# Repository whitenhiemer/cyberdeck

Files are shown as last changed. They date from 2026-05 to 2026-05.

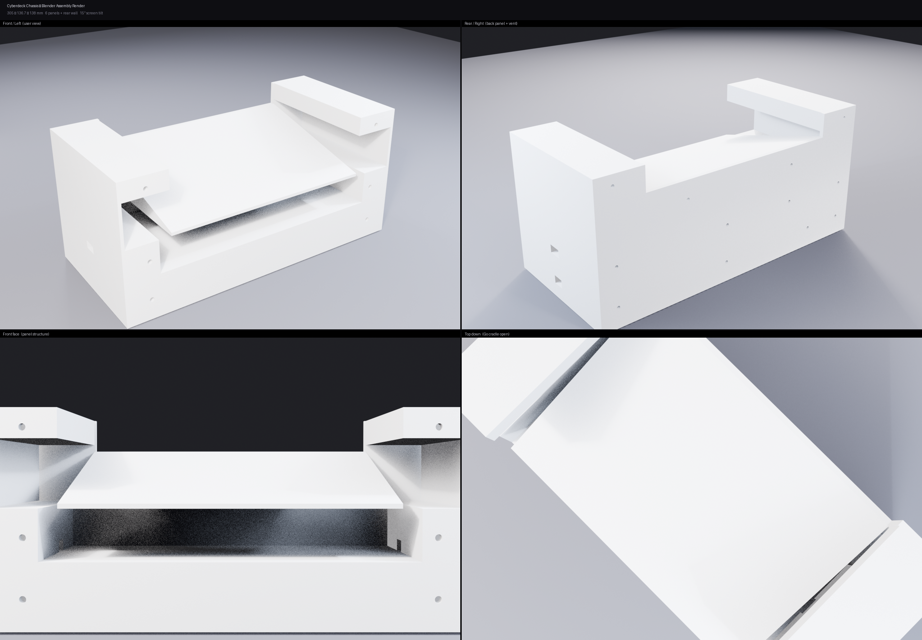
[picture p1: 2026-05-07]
cad/chassis_blender.png

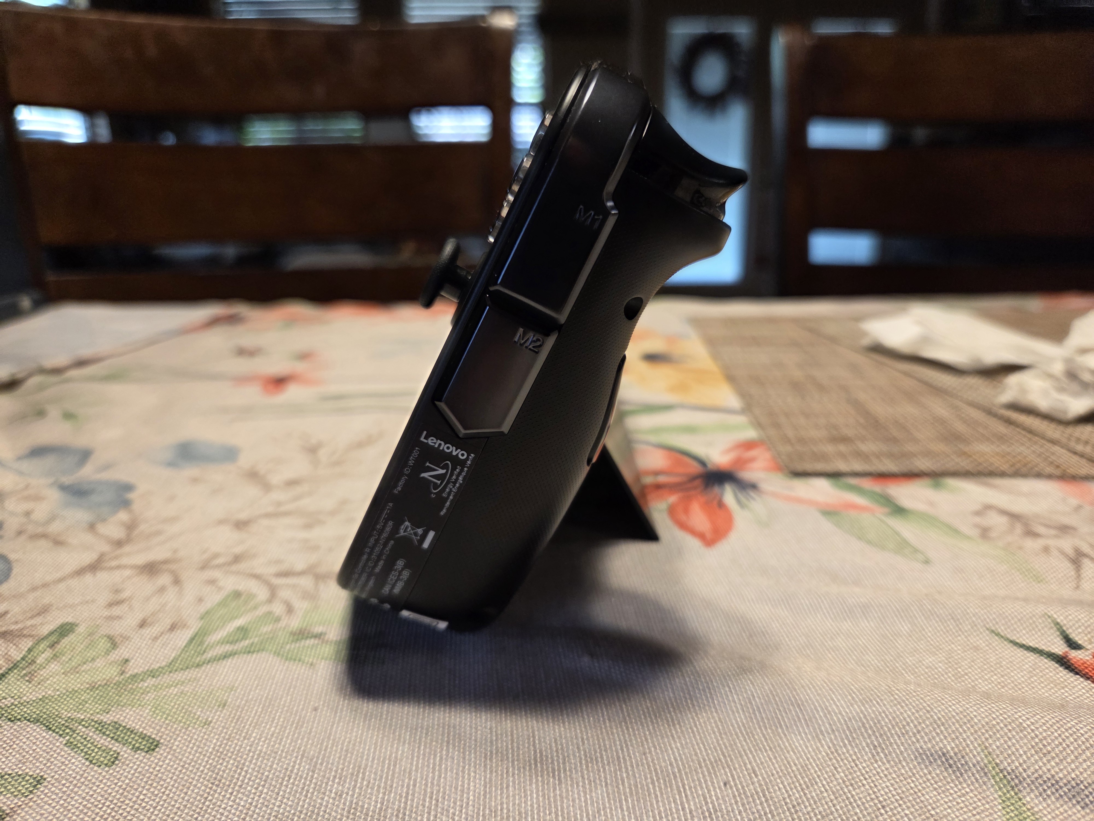
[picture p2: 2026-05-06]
photos/20260506_140101.jpg

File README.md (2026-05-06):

# Cyberdeck

A 3D-printed chassis that turns a Lenovo Legion Go into a portable cyberdeck workstation. Non-destructive — the Go sits in a cradle and can be removed.

## Hardware

| Component | Model | Dimensions |
|---|---|---|
| Brain | Lenovo Legion Go (83E1, 8APU1) | 298.83 x 131 x 40.7mm (with controllers) |
| Keyboard | Planck V7 (USB-C) | 234 x 81 x 33mm |
| Hub | MOKiN 13-in-1 USB-C dock | 130 x 55 x 15mm |
| Battery | OHOVIV 50000mAh power bank | 134 x 70 x 34mm |
| Printers | Ender 3 / Ender 5 | 220x220mm bed |

## Design

- **Form:** Landscape slab, three horizontal rows
- **Tilt:** 15° wedge cradle for the Go (screen angles toward user)
- **Controllers:** Detachable — chassis side channels open at bottom for slide-out removal
- **Back:** Closed rear wall with open vent cutout behind Go exhaust; 5mm kickstand clearance gap
- **Battery:** Removable sliding bay, exits from bottom edge

```
┌──────────[A]──────────┬──────────[B]──────────┐  ← Go cradle (62mm tall)
│  controller rail (L)  │  controller rail (R)  │
│    [ Legion Go cradle — 15° wedge ]            │
├──────────[C]──────────┬──────────[D]───────────┤  ← Planck + dock (36mm tall)
│    [ Planck bay ]     │  [ dock bay ]          │
├──────────[E]──────────┴──────────[F]───────────┤  ← Battery (40mm tall)
│       [ battery bay — slides out from bottom ] │
└────────────────────────────────────────────────┘
  Total: 305 x 138mm face, ~314mm front-to-back
```

## CAD

FreeCAD Python macros in `cad/`. Each panel is a standalone script — open FreeCAD, run the macro via **Macro → Macros**, and it generates and saves the `.FCStd` file.

| File | Description |
|---|---|
| `panel_a.py` | Go cradle, left half — wedge cavity + left controller channel |
| `panel_b.py` | Go cradle, right half — wedge cavity + right controller channel |
| `panel_c.py` | Planck bay, left half |
| `panel_d.py` | Planck bay, right half (dock bay on right) |
| `panel_e.py` | Battery bay, left half |
| `panel_f.py` | Battery bay, right half (USB-C port cutout) |
| `rear_wall.py` | Rear structural wall with Go exhaust vent cutout |

All panels use M3 bolts + alignment pins at seams (holes TBD once final dimensions are locked).

## Open Items

- [ ] Controller rail groove cross-section — needs calipers on Go side edge
- [ ] Final chassis outer dimensions
- [ ] Panel split lines and fastener locations
- [ ] Model controller rail extensions (left + right)
- [ ] Add M3 bolt holes and alignment pins at seams
- [ ] Internal cable routing (Planck USB-C → dock)

## Reference Photos

`photos/` — Legion Go back face, side rail profile, controller connection end.

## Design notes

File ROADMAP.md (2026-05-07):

# Cyberdeck Build Roadmap

## Hardware

- **Brain:** Lenovo Legion Go (83E1, 8APU1)
- **Keyboard:** Planck (USB-C)
- **Hub:** MOKiN 13-in-1 USB-C docking station
- **Printers:** Ender 3 / Ender 5 (220x220mm bed)

## Design Spec

| Element | Decision |
|---|---|
| Form factor | Landscape slab |
| Integration | Non-destructive (Legion Go cradle) |
| Controllers | Detachable, re-attachable via side rails |
| Keyboard | Planck integrated, internal USB-C routing |
| Hub | MOKiN 13-in-1, ports exposed on right edge |
| Screen tilt | 10-15° wedge cradle |
| Back | Closed, structural rear wall |
| Dock placement | Rear wall cavity (ports → right edge cutouts) |
| Battery | OHOVIV 50000mAh, 3rd row, removable sliding bay (exits bottom edge) |
| Handle | Top bar (primary); recessed side grip (backup/iteration) |
| Aesthetic | Utilitarian / functional |

## Known Dimensions

| Component | Dimensions (mm) | Notes |
|---|---|---|
| Legion Go (with controllers) | 298.83 x 131 x 40.7 | 854g |
| Legion Go (base only) | 210 x 131 x 20.1 | 640g |
| Controller (each) | 44.8 x 136.7 x 42.25mm | 210g, own 900mAh battery |
| Controller width per side | ~44.4mm | matches (298.83 - 210) / 2 |
| Controller overhang (height) | +5.7mm over Go base | 136.7mm vs 131mm — protrudes top/bottom |
| Controller thickness overhang | +1.55mm over Go body | 42.25mm vs 40.7mm — bulges beyond Go profile |
| Controller connection | Pogo pins + physical rail | no electrical replication needed in chassis |
| Planck keyboard (V7) | 234 x 81 x 33mm | 510g assembled, 19mm key spacing |
| MOKiN dock | 130 x 55 x 15mm | built-in USB-C cable 6-8", ports on both long sides |
| OHOVIV 50000mAh power bank | 134 x 70 x 34mm | 613g, 22.5W, USB-C + 2x USB-A |

## Chassis Estimates

| Dimension | Value | Basis |
|---|---|---|
| Chassis width | ~305mm | Go full width + side walls |
| Chassis depth (Y) | 136.7mm | All rows unified — set by controller front-to-back extent |
| Chassis height | ~314mm | 131mm Go + ~93mm Planck + ~80mm battery + seams |
| Panel half width | ~150mm | fits 220mm bed |
| Back wall height (at 15°) | +35mm over front | tan(15°) × 131mm |
| Total weight (est.) | ~2.3kg | Go 854g + Planck 510g + bank 613g + chassis ~300g |

## Panel Layout

```
┌──────────[A]──────────┬──────────[B]──────────┐
│  controller rail (L)  │  controller rail (R)  │
│    [ Legion Go cradle (wedge, 10-15°) ]        │
├──────────[C]──────────┬──────────[D]───────────┤
│    [ Planck bay ]     │  [ dock bay ]          │
│                       │  (ports → right edge)  │
├──────────[E]──────────┴──────────[F]───────────┤
│       [ battery bay — slides out from bottom ] │
└────────────────────────────────────────────────┘
```

Side profile:
```
         ____________
        /  Go screen \  ← 10-15° tilt
       /   (20.1mm)  \
______/________________\______
[    Planck    ] [ dock  ]       ← flat base
```

## Phase 1 — Measurements & Dimensions

- [x] Legion Go body dimensions (base + with controllers)
- [x] Controller rail mechanism (slide top-to-bottom, latch at bottom — Joy-Con style)
- [ ] Controller rail groove profile (cross-section depth/width — requires calipers on Go side edge)
- [x] Planck keyboard outer dimensions (234 x 81 x 33mm with acrylic case)
- [x] MOKiN dock outer dimensions (130 x 55 x 15mm)
- [x] Verify screen area is not obstructed — cradle open at y=0, 5.4mm above screen rear edge, 11mm side clearance
- [ ] Define final chassis outer dimensions
- [ ] Determine exact tilt angle (10-15°)
- [ ] Define panel split lines and fastener locations

## Phase 2 — CAD Design

- [x] Choose CAD tool (FreeCAD macros)
- [x] Model panel A — Go cradle top-left
- [x] Model panel B — Go cradle top-right
- [x] Model panel C — Planck bay bottom-left
- [x] Model panel D — dock bay bottom-right
- [x] Model controller rail extensions (left + right) — groove profile placeholder, needs calipers
- [x] Model rear wall / closed back
- [x] Add M3 heat insert holes and alignment pins at panel seams
- [x] Internal cable routing channels (Planck USB-C → dock)
- [x] Model horizontal seam angle bracket clips (separate printed parts, 2 per seam × 2 seams = 4 total)
- [x] Round all sharp external edges — 1.5mm chamfer on front-face and outer-side corners (apply_chamfers.py)
- [x] Fit check / dry assembly review (62/62 software geometry checks pass)

## Variant: No-Rails (cad/no-rails/)

Alternative design for use as handheld — controllers detach and the Go is removed from the chassis entirely.

- [x] Panel A/B without controller rail channels (`cad/no-rails/panel_a.py`, `panel_b.py`)
- [x] Geometric fit check (18/18 pass — same rear wall, brackets, C–F panels)
- [x] Chamfer script for no-rails A/B (`cad/no-rails/apply_chamfers.py`)
- Panels C, D, E, F, rear_wall, bracket_clip — unchanged, use main `cad/` versions

Key difference: 46.5mm solid outer walls in place of 3mm wall + 40mm controller pocket. Go base (210mm) cradles identically; controllers are not accommodated.

## Phase 3 — Prototyping

- [ ] PLA first for fit/tolerance verification, then professional ABS or acrylic print for final
- [ ] Print test pieces at panel seams (fit tolerances)
- [ ] Print controller rail mockup
- [ ] Adjust tolerances based on test prints
- [ ] Print full panels (likely 8-12 hour prints each)
- [ ] Dry fit all panels with hardware

## Phase 4 — Assembly

- [ ] Install M3 heat-set inserts
- [ ] Mount Legion Go in cradle
- [ ] Mount Planck in bay
- [ ] Mount dock in bay, route USB-C to Go
- [ ] Attach controller rails
- [ ] Final fit and finish (sanding, filler if needed)

## Phase 5 — Iteration

- [ ] Evaluate ergonomics (tilt angle, keyboard position)
- [ ] Evaluate top bar handle — if awkward, model recessed side grip variant
- [ ] Add any cable management details
- [ ] Consider paint / surface finish
- [ ] Document final design for reproducibility

## Notes

- All panel seams use M3 bolts + alignment pins
- Machine-specific local configs (Go firmware, etc.) never committed
- Controller rails: slide downward to remove — chassis side channels open at bottom
- Controllers are 5.7mm taller than Go base — top bar must clear controller tops
- Controller thickness (42.25mm) slightly exceeds Go body (40.7mm) — side channel needs clearance
- Pogo pins handle electrical connection — chassis only needs to replicate physical rail groove
- Rail groove cross-section still needs calipers before finalizing side panel CAD
- Battery bay slides out from bottom edge; USB-C port exposed via cutout, dock cable connects manually
- Battery bay retention: printed latch or M3 thumb screw

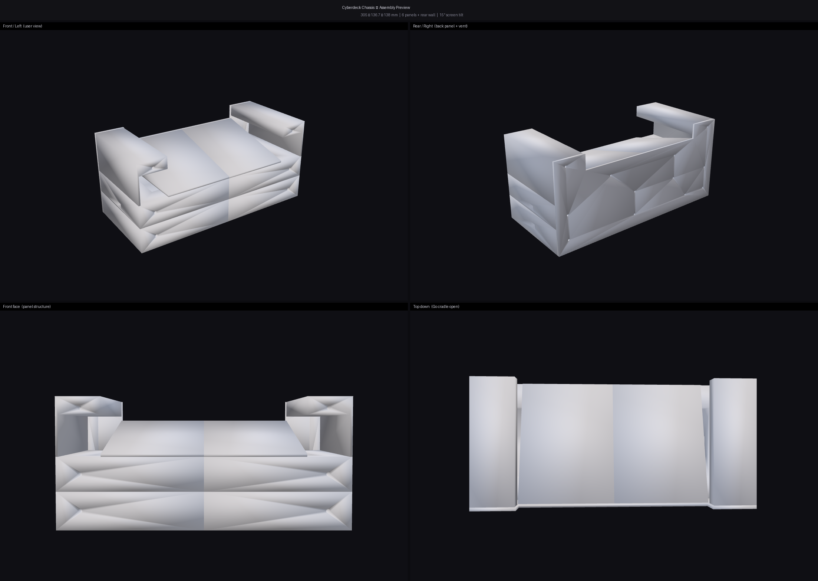
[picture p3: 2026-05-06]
cad/chassis_hq.png

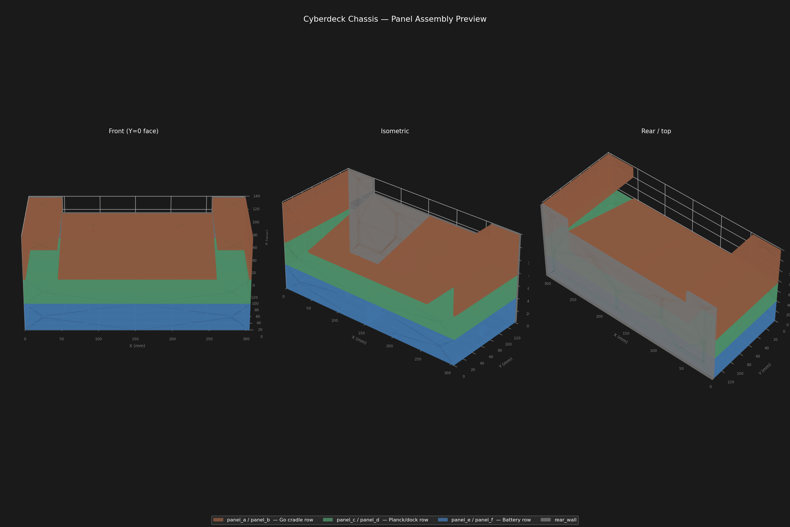
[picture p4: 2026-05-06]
cad/chassis_preview.png

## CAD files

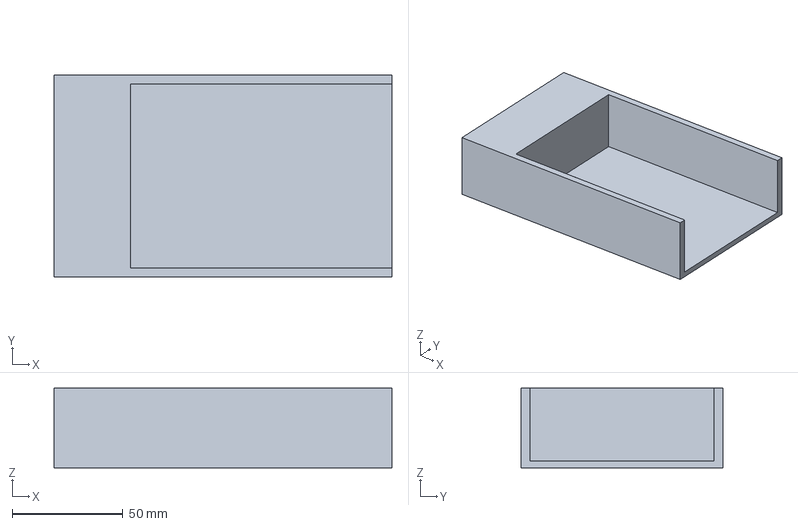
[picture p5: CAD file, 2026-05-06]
cad/panel_c.FCStd
152.5 x 91.0 x 36.0 mm

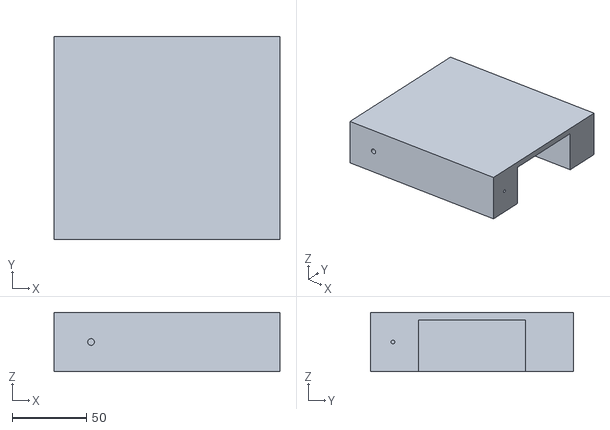
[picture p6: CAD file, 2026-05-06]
cad/stl/panel_e.stl
152.5 x 136.7 x 40.0

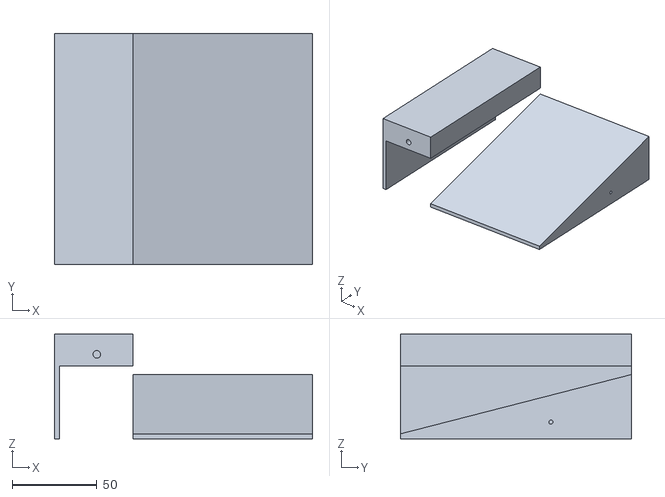
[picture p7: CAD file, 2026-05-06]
cad/stl/panel_a.stl
152.5 x 136.7 x 62.0

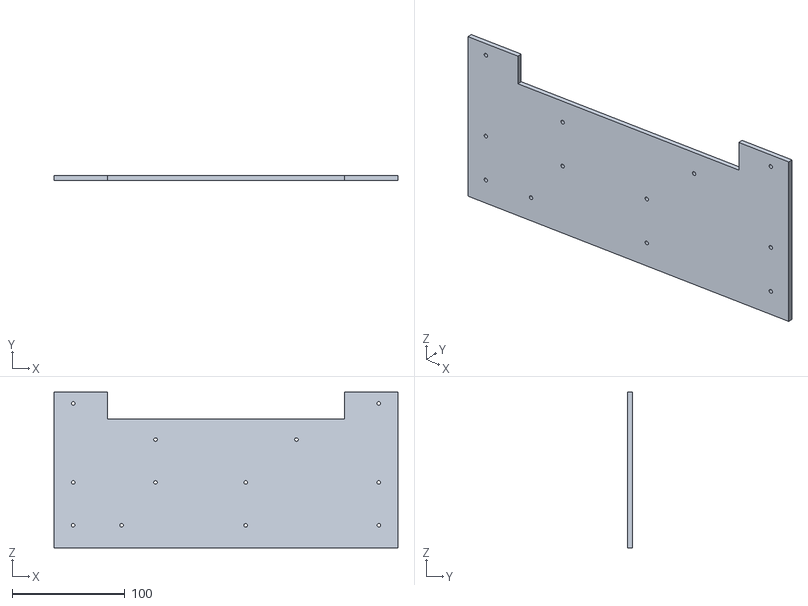
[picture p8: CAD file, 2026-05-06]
cad/stl/rear_wall.stl
305.0 x 4.00 x 138.0

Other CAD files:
cad/panel_d.FCStd
cad/stl/panel_f.stl
cad/stl/panel_b.stl
cad/stl/panel_c.stl
cad/stl/panel_d.stl

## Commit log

2026-05-06 Initial cyberdeck project roadmap
    Legion Go slab cyberdeck with integrated Planck keyboard and MOKiN dock.
    Non-destructive chassis, 10-15° screen tilt, 4-panel split for Ender 3/5.
2026-05-06 Add Legion Go dimensions and chassis estimates to roadmap
    Known dimensions populated for Go base and with-controllers measurements.
    Chassis estimated at ~305x234mm, panel halves ~150mm (fits 220mm bed).
2026-05-06 Add Planck V7 dimensions to roadmap
    234x81x33mm with acrylic case. Planck thickness (33mm) exceeds Go base
    (20.1mm) — Planck section becomes structural floor of the slab.
2026-05-06 Add OHOVIV power bank to roadmap
    134x70x34mm, 613g, 50000mAh. Placement TBD — 3rd row adds ~80mm to
    chassis height; rear compartment is tight at 70mm wide. ~2.3kg total.
2026-05-06 Add battery row layout: 6-panel chassis, removable sliding bay
    Battery slides out from bottom edge with latch/thumb screw retention.
    Chassis height grows to ~314mm, est. total weight ~2.3kg.
2026-05-06 Document controller rail mechanism: slide down to remove
    Controllers detach by sliding downward (not upward). Chassis side panels
    need channels open at the bottom. Rail profile dimensions still TBD.
2026-05-06 Add full controller specs and design implications
    Controllers: 44.8x136.7x42.25mm, 210g each, own 900mAh battery.
    Key constraints: 5.7mm height overhang over Go base (affects top bar),
    1.55mm thickness overhang (affects side channel clearance).
    No electrical replication needed — pogo pins are Go-native.
2026-05-06 Add cad/ directory and gitignore for FreeCAD files
2026-05-06 Add Panel C FreeCAD macro (Planck bay, left half)
    Parametric Part workbench script: 152.5x91x36mm panel with 33mm deep
    Planck pocket (118x83mm in left panel, continues into Panel D).
2026-05-06 Add Panel D FreeCAD macro (Planck bay, right half)
    118mm Planck pocket from seam face, 34.5mm solid right outer wall.
    Mates with Panel C to form complete 236x83x33mm Planck recess.
2026-05-06 Add Panel E+F FreeCAD macros (battery bay row)
    Open-bottom tray, 136x72x35mm cavity (1mm clearance).
    Battery centered in chassis, 5mm top wall, 68mm per panel half.
    Panel F includes USB-C port cutout on right face.
2026-05-06 Add Panel A+B FreeCAD macros (Go cradle row)
    Wedge cradle at 15° tilt (parameterized via TILT_DEG), controller rail
    placeholder channels open at bottom for slide-out removal. Cavity and
    controller pocket dimensions are symmetric across the A/B seam.
2026-05-06 Add rear wall macro and reference photos
    Rear wall: 305 x 4 x 138mm, open vent cutout (210 x 24mm) aligned to
    Go exhaust zone. 5mm kickstand clearance gap between panel rear face and
    wall inner face keeps kickstand protected without blocking airflow.
    Photos: Go back face, side rail profile, controller connection end.
2026-05-06 Add README
    Hardware specs, chassis layout, CAD macro index, and open items list.
2026-05-06 Add USB-C cable routing channels to Panel C and D
    14x8mm slot through Panel C left wall and Panel D right wall, centered
    in the Planck pocket, flush with the pocket floor. Sized to pass a
    USB-C connector for tool-free keyboard and battery replacement.
2026-05-06 Add M3 heat insert holes and alignment pins to all panels
    All panels: rear face heat insert holes (4.5mm dia x 6mm) at positions
    verified clear of all pockets — rear wall M3 bolts are the primary
    structural connection. Alignment pin holes (2.5mm dia x 5mm) at each
    vertical seam face, y=89mm rear margin (only zone solid across all rows).
    Rear wall: 12 matching M3 clearance holes (3.2mm) at all insert positions.
    [panel_c.FCStd, panel_d.FCStd]
2026-05-06 Update Phase 2 roadmap: mark completed items, add angle bracket clips
2026-05-06 Add angle bracket clips and front face inserts
    bracket_clip.py: two bracket sizes (76mm for AB-CD seam, 46mm for CD-EF
    seam), 20x4mm cross-section, M3 clearance holes at each end. Print 2x
    each. Mount to chassis front face with M3x10 bolts into panel inserts.
    All panels: front face heat insert holes (4.5mm x 6mm) at positions
    verified solid at y=0. Panel C/D insert at z=18mm serves both brackets
    (shared position). Brackets span the horizontal seams without modifying
    the panel geometry beyond adding these insert holes.
2026-05-06 Add controller rail extension guide macro (rail_ext.py)
    Press-fit guide blocks for left and right controller pockets in AB panels.
    8mm extension below panel face with Go-side-rail groove (placeholder profile),
    4mm retention tab, and 45° entry chamfer for alignment on controller re-attachment.
    Groove profile marked as placeholder pending caliper measurement of Go side rail.
    Mark rail extensions and angle bracket clips as complete in ROADMAP.
2026-05-06 Add STL exports, render script, and chassis preview image
    Add export_stl.py (FreeCADCmd batch exporter), render_chassis.py
    (trimesh + matplotlib 3-view assembly render), and generated STL/PNG
    outputs. Update .gitignore to exclude FCStd and pycache. Add edge
    rounding to Phase 2 roadmap.
    [panel_a.stl, panel_b.stl, panel_c.stl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]
2026-05-06 Unify all panel rows to 136.7mm depth for flat rear wall
    Set PANEL_H=136.7 on panels C, D, E, F (was 91mm). All rows now match
    the AB row depth set by controller front-to-back extent. Moves alignment
    pins from y=89 (now inside Planck pocket / battery cavity) to y=15 (solid
    front section for all affected panels). Updates rear wall render position.
    Adds screen-area verification and PLA-first prototyping notes to roadmap.
    Regenerates all STLs and chassis preview image.
    [panel_c.stl, panel_d.stl, panel_e.stl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]
2026-05-06 Mark screen clearance check complete
    Verified: cradle front face open (wedge cut to y=0), 5.4mm Z clearance
    above screen rear edge, 11mm X clearance to screen edges. Assembly note:
    lower Go rear-edge-first to work with 3.8mm body clearance at rear.
2026-05-06 Add pyrender-based high-quality chassis render (render_hq.py)
    4-view composite (front-left iso, rear-right iso, front face, top-down)
    using EGL offscreen pyrender with directional lighting and PBR material.
    Replaces matplotlib placeholder as primary assembly preview.
2026-05-06 Add Blender headless render script and output (EEVEE, 4-view composite)
    blender_render.py imports all 7 STLs, applies PBR matte PLA material,
    3-point area lighting, fast GI, and renders front-iso, rear-iso, front-face,
    and top-down views. Composited to chassis_blender.png via PIL.
2026-05-06 Add outer edge chamfers to all panels (apply_chamfers.py)
    1.5mm chamfer on user-visible outer corners: front face (y=0) and outer
    side face for all 6 panels. Seam faces (rear wall, left/right panel seam,
    row-mating z-faces) left sharp for precise panel registration. Chamfers
    computed geometrically by finding straight edges at the intersection of 2+
    bounding-box planes. Updates STLs and re-renders chassis preview.
    [panel_a.stl, panel_b.stl, panel_c.stl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]
2026-05-07 Add front-face keyboard throat to panels C and D
    Cuts a 26.85mm-deep throat (y=0 to planck_y) in the front face of the CD
    row at the Planck pocket X/Z extent, opening the keyboard bay to the user.
    Creates a recessed keyboard bay with a natural palm-rest depth.
    Moves alignment pins from y=15 (now inside throat) to y=120 (rear solid
    section, past pocket rear wall at y=109.85mm).
    [panel_a.stl, panel_b.stl, panel_c.stl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]
2026-05-07 Add software geometric fit check; fix stale battery_y comments
    62/62 checks pass covering: seam pin symmetry, all fasteners in solid
    material (including post-throat-cut validation), rear wall bolt hole
    alignment, bracket span verification, and Planck pocket continuity.
    Fix stale 9.5mm→32.35mm battery_y comment in panel_e/f.py (value
    changed when PANEL_H unified to 136.7mm).
2026-05-07 Add no-rails variant (panels A/B without controller rail channels)
    For use when the Go is removed from the chassis to play as a handheld.
    Controller rail pockets removed; left/right outer walls become 46.5mm
    solid blocks. Go cradle, all fastener positions, bracket spans, and
    rear wall bolt holes are unchanged (18/18 fit checks pass).
